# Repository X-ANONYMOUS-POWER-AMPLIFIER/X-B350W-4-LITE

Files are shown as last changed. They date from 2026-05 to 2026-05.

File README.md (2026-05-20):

# X-B350W-4-LITE - SIMPLIFIED MAIN-CIRCUIT MODULE OF 350 WATTS CLASS-B AUDIO POWER AMPLIFIER MAIN-CIRCUIT FOR 4-OHMS OUTPUT LOAD

X-B350W-4-LITE is a power amplifier main-circuit module designed to handle 350 watts of 4-ohms output load power rating. The circuit of X-B350W-4-LITE applies only the effective circuitry models for each of its blocks. Its input-stage applies a minimalist-but-effective LTP (Long Tailed Pair) circuit model, completed with an active-load and an offset null adjustment trimmer. Its VAS (Voltage Amplifier Stage) applies a simple circuit model but with an advanced active-load technique to achieve high amplification performance, with applies only few number of transistors without needing to apply differential-based topology.

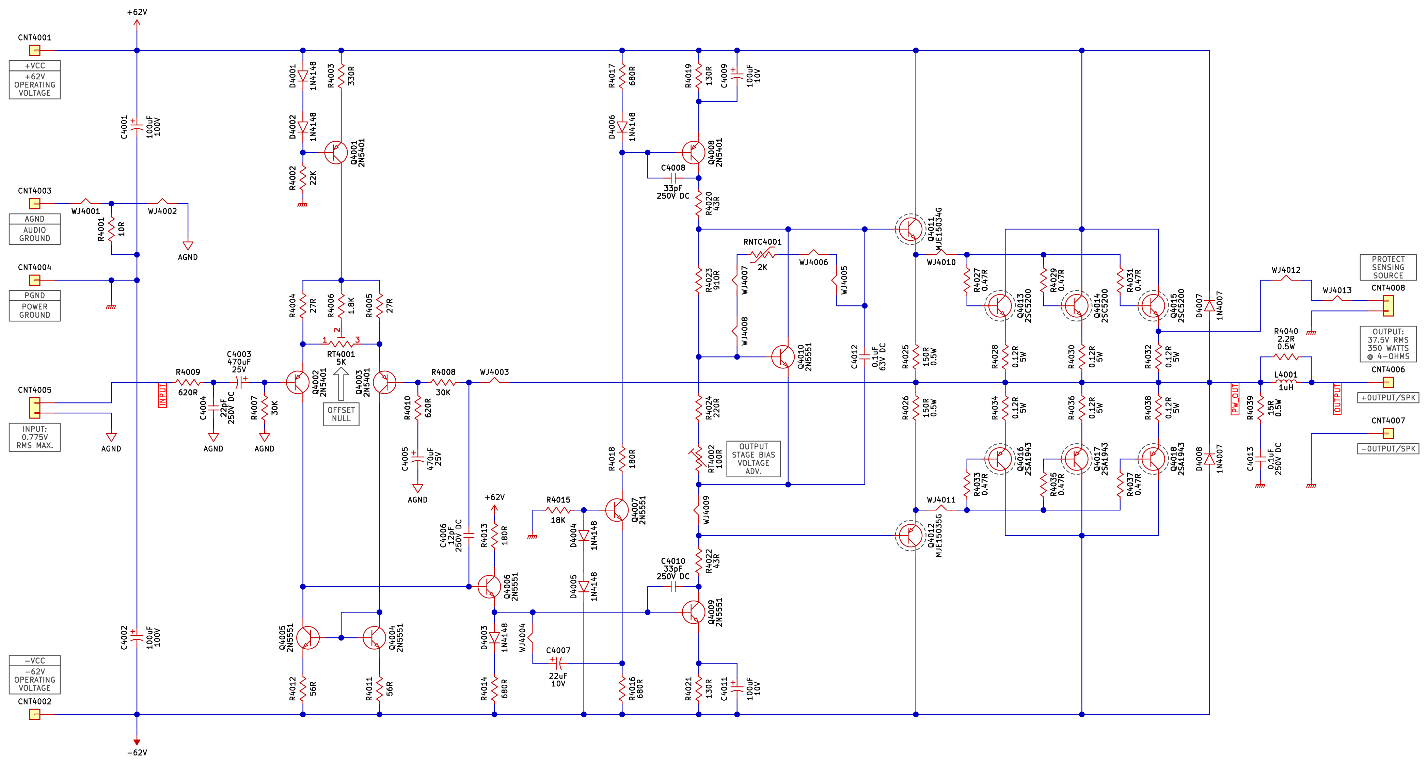
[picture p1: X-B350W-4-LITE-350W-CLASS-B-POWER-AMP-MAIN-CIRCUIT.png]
X-B350W-4-LITE schematic diagram


## Advanced VAS Model

The VAS of this power amp main-circuit model has an active load that synchronized with the main VAS side to be working as well a fully symmetrical VAS. The output signal from the LTP buffer (Q4006's emitter) copied by a grounded-base transistor amplifier or signal-current-buffer, Q4007, to feed a copy of signal for VAS's loader, Q4008, makes the VAS's loader to be fully actively working side-by-side with the main VAS, Q4009.

The amplification workflow between LTP buffer, Q4006, into the VAS loader, Q4008, isn't for tackling the DC amplification, but limited for tackling AC amplification. The LTP buffer output, Q4006's emitter, is coupled by C4007 into the emitter of Q4007 for gaining the AC signal only, thus Q4007 can keep its main function as a current-source to provide a constant forward-bias-current for Q4008's base and thus Q4008 also kept its function as a current-source for providing the initial constant forward-bias-current for the output-stage while it is also taking function as an active loader of VAS for providing fully symmetrical AC amplification.

There are 3 nodes of NFB lag compensations applied as C4006, C4008, and C4010, to achieve high performance in high frequency amplification (10kHz ~ 15kHz). C4006 compensates the NFB lag for LTP output buffer, Q4006, eliminates non-linear EF buffering. C4008 compensates the NFB lag for high-side VAS, Q4008, eliminates non-linear voltage amplification. C4010 compensates the NFB lag for low-side VAS, Q4009, eliminates non-linear voltage amplification.

By applying this technique, this power amp main-circuit model will be able to achieve wide headroom even for 1-ohms load in fully symmetrically and certainly achieve high performance in nominal output load (4-ohms or 8-ohms). And certainly, one of the important tings is about limit the number of transistors, makes the X-B350W-4-LITE circuit model quit simple with high performance guarantee.

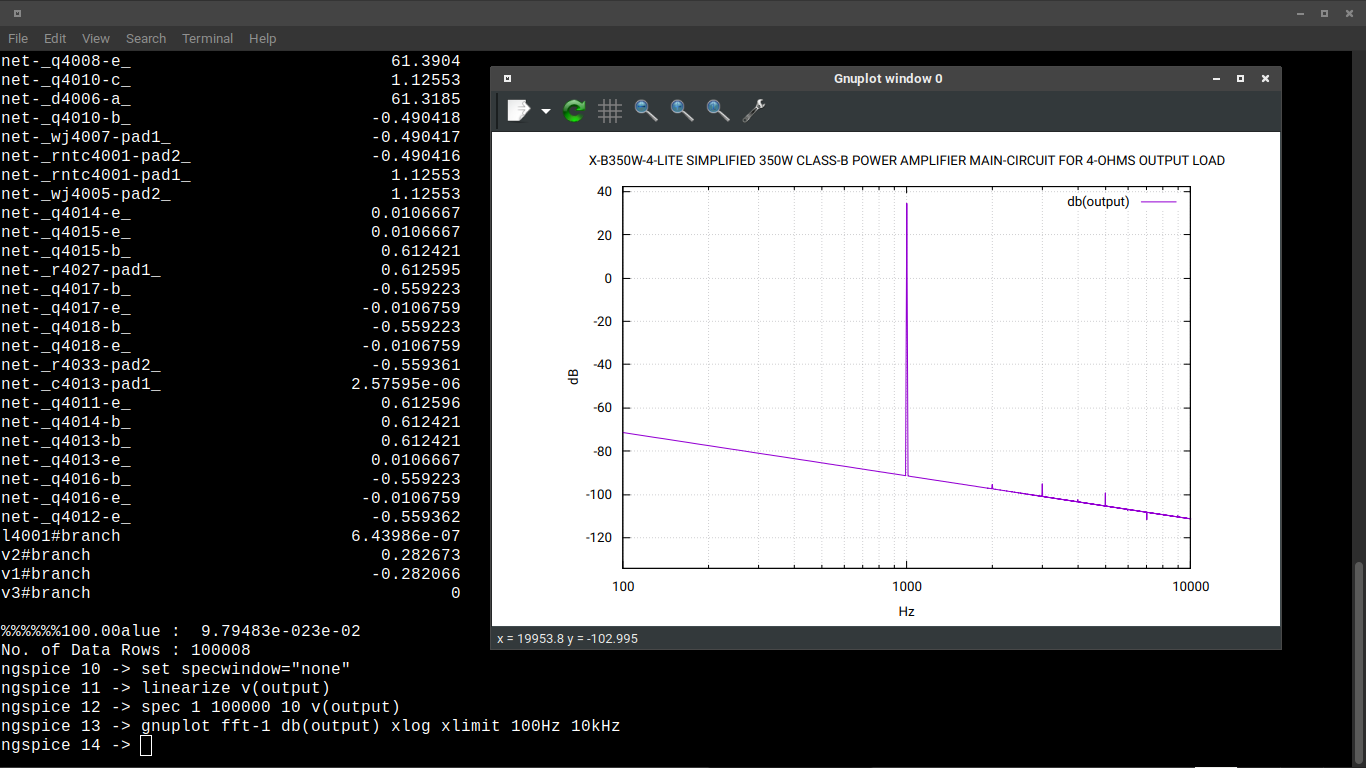
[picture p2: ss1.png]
FFT analysis 1

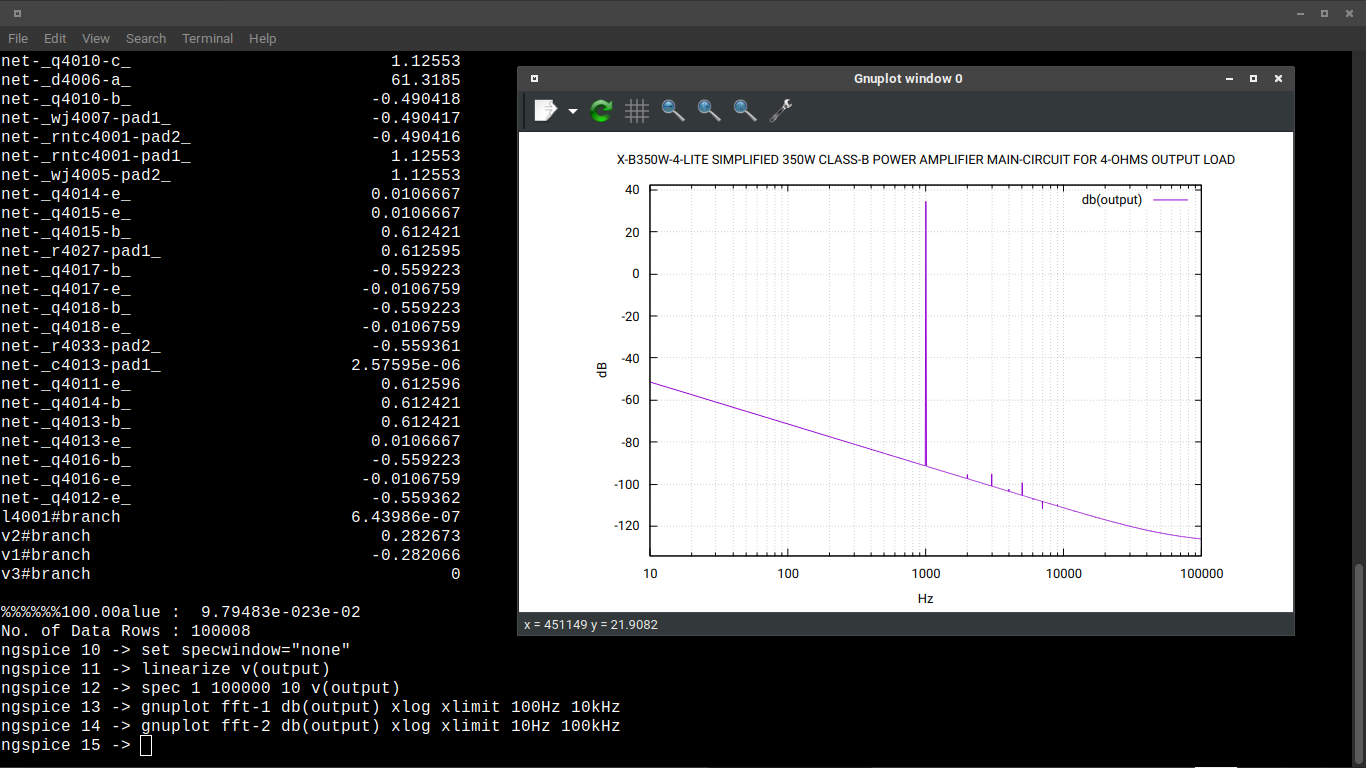
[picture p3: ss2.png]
FFT analysis 2

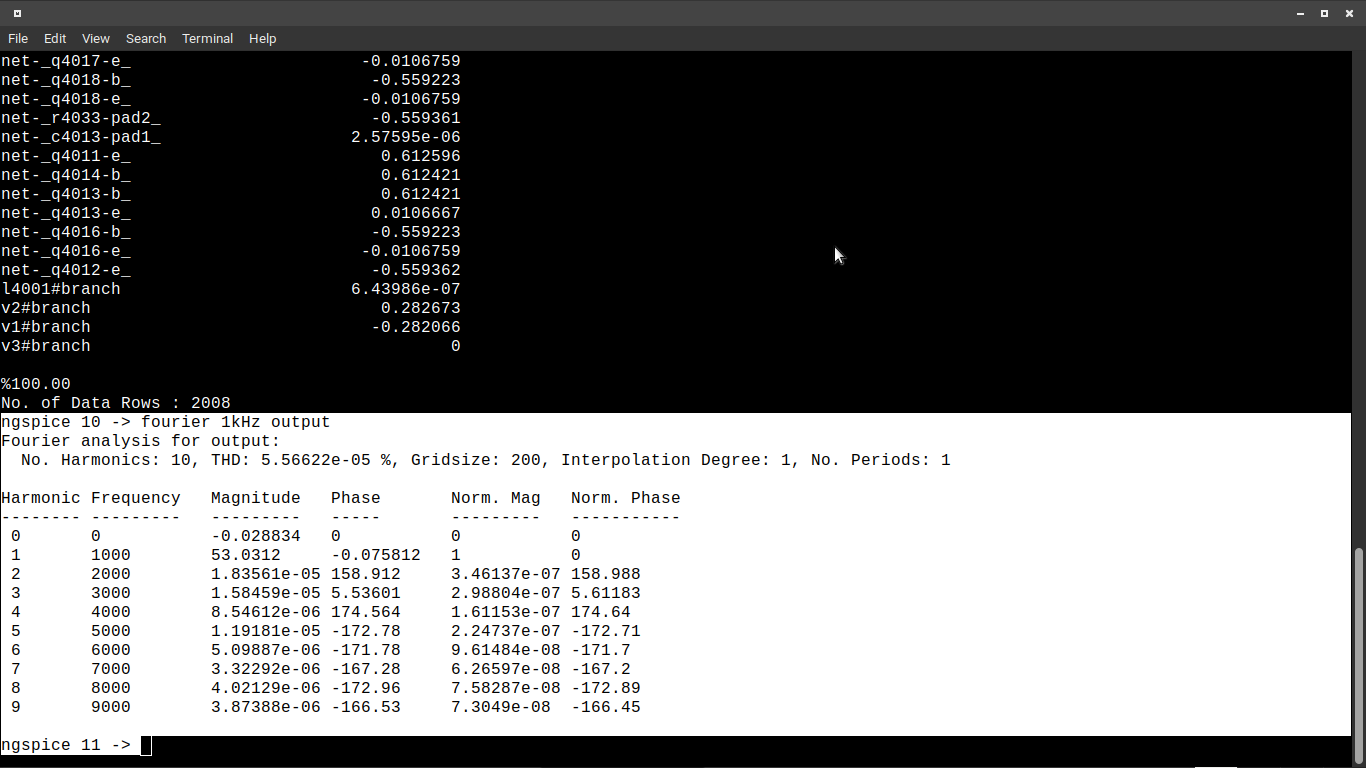
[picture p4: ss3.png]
Fourier analysis 1

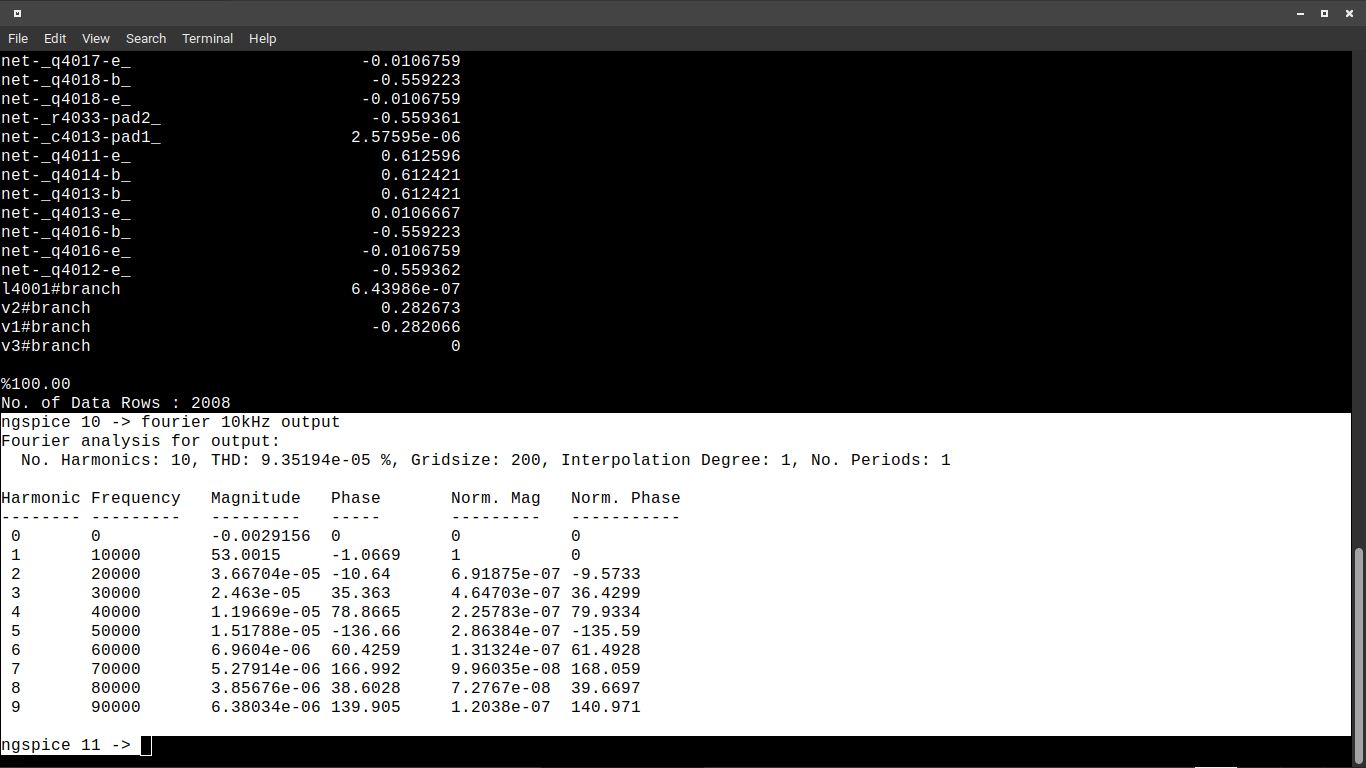
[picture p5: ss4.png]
Fourier analysis 2


## Warning: None of Current-Limiter Applied Within The Output-Stage

There is none of current-limiter applied within the output-stage, means that it may introduce a risk of short-circuited output. To prevent a fatal output short-circuited overcome, an output protection circuit have to be applied between the X-B350W-4-LITE module's +SPK output and the loudspeaker. The sensing signal of the overload output or output short-circuit can be obtained via CNT4008.

You may have a question, why none of current-limiter applied within the output-stage? The answer is: Applying the current-limiters within the output-stage, as it commonly applied "just to drop the signal amplitude of the output-stage driver transistor bases" - is not really effective since the VAS will always maintain its signal-current along to follow its amplification level although the current-limiter actives as it detects a short-circuited output.

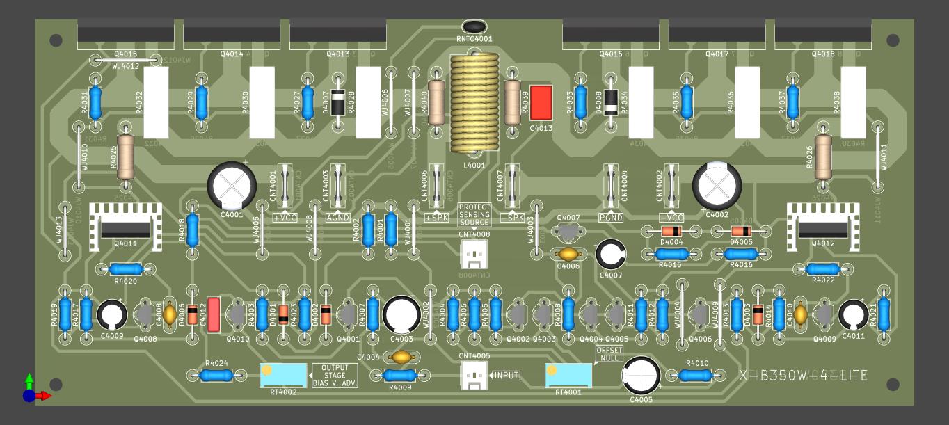
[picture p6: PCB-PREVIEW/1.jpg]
Circuit board preview 1

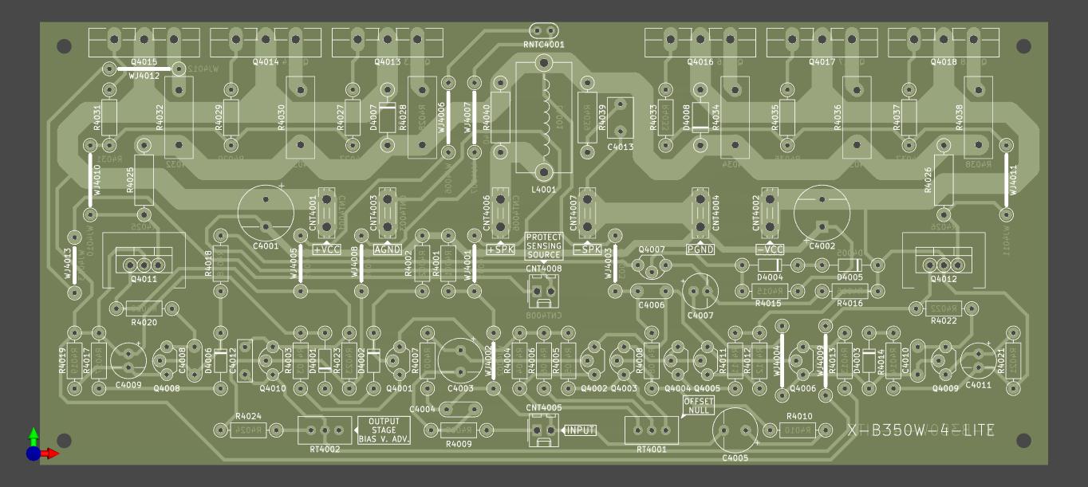
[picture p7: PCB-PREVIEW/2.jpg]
Circuit board preview 2

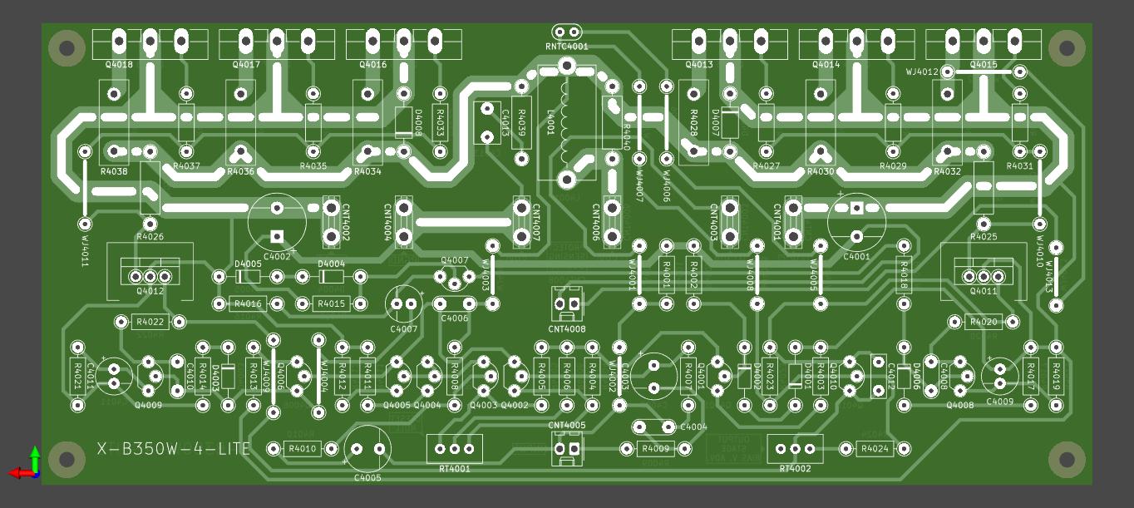
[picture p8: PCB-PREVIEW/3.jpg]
Circuit board preview 3

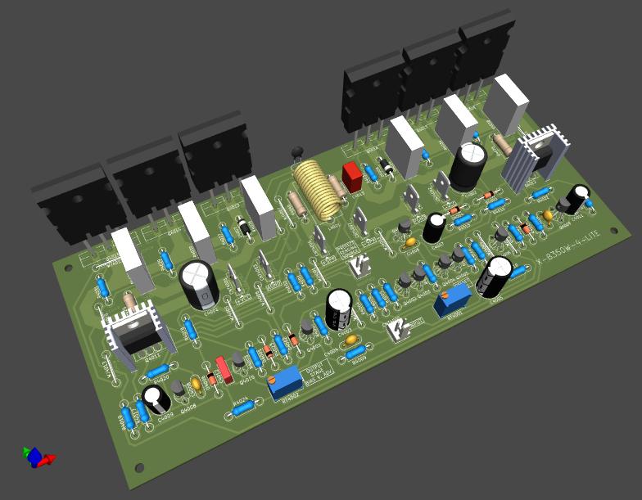
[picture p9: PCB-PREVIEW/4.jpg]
Circuit board preview 4

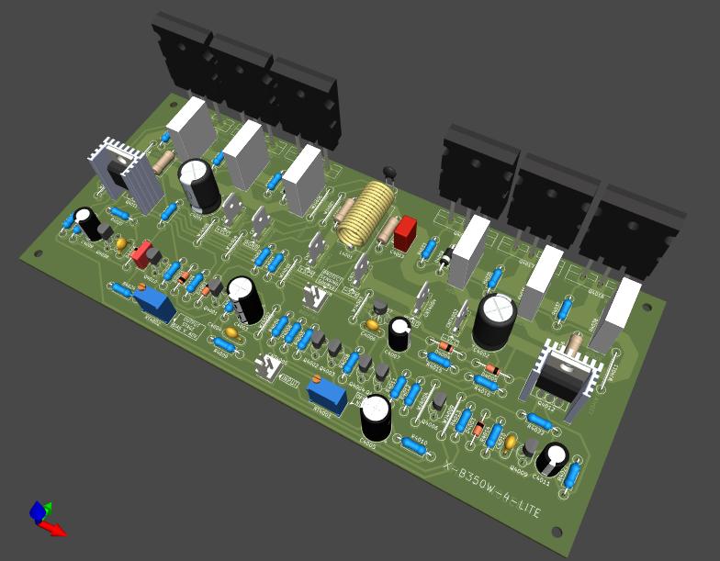
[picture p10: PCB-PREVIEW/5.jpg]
Circuit board preview 5


## License

1. **License Grant**  
The Licensor hereby grants you a worldwide, royalty-free, non-exclusive, perpetual license to use the circuit design for the non-commercial purposes only.
2. **Conditions**  
Attribution: You must provide credit to the original creator when distributing this circuit design.
3. **Disclaimer of Warranty**  
THE DESIGN IS PROVIDED "AS IS". THE LICENSOR MAKES NO WARRANTIES, EXPRESS OR IMPLIED, REGARDING THE DESIGN, INCLUDING BUT NOT LIMITED TO ANY IMPLIED WARRANTIES OF MERCHANTABILITY OR FITNESS FOR A PARTICULAR PURPOSE.
4. **Limitation of Liability**  
IN NO EVENT SHALL THE LICENSOR BE LIABLE FOR ANY DAMAGES, INCLUDING BUT NOT LIMITED TO DIRECT, INDIRECT, INCIDENTAL, OR CONSEQUENTIAL DAMAGES ARISING OUT OF THE USE OF THE DESIGN.

# Design Files Bundle Download

Design files bundle is available for download by follow the URL: [https://github.com/X-ANONYMOUS-POWER-AMPLIFIER/X-B350W-4-LITE/archive/refs/heads/main.zip](https://github.com/X-ANONYMOUS-POWER-AMPLIFIER/X-B350W-4-LITE/archive/refs/heads/main.zip)

The main design files of schematic and PCB design are in [KiCad](https://www.kicad.org/) V.9.x format.

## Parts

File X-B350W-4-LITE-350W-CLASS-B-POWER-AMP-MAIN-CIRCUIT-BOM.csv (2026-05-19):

Reference | Value | Rating | Description | MFR Number | Manufacturer | Qty
C4001,C4002 | 100uF | 100V | Aluminum Electrolytic Capacitors - Radial Leaded 100uF 100V | ECA-1EM100I | Panasonic | 2
C4003,C4005 | 470uF | 25V | Aluminum Electrolytic Capacitors - Radial Leaded 470uF 25V | EEU-FC1E471L | Panasonic | 2
C4004 | 22pF | 250V DC | Multilayer Ceramic Capacitors MLCC - Leaded 22PF 50V 5% 5.0MM | RDE5C1H220J0K1H03B | Murata | 1
C4006 | 12pF | 250V DC | Multilayer Ceramic Capacitors MLCC - Leaded 250V 22pF C0G 5% LS=5.08mm | C323C120JAG5TA | KEMET | 1
C4007 | 22uF | 10V | Aluminum Electrolytic Capacitors - Radial Leaded 10VDC 22uF POLARIZED | ECE-A1AKS220I | Panasonic | 1
C4008,C4010 | 33pF | 250V DC | Multilayer Ceramic Capacitors MLCC - Leaded 250V 33pF C0G 5% LS=5.08mm | C323C330JAG5TA | KEMET | 2
C4009,C4011 | 100uF | 10V | Aluminum Electrolytic Capacitors - Radial Leaded 100uF 10V | ECE-A1AKA101 | Panasonic | 2
C4012 | 0.1uF | 63V DC | Film Capacitors 0.1 uF 63 VDC 5% | MKS2C031001A00JI00 | WIMA | 1
C4013 | 0.1uF | 250V DC | Film Capacitors 0.1 uF 250 VDC 20% | MKS2F031001E00MSSD | WIMA | 1
CNT4001,CNT4002,CNT4003,CNT4004,CNT4006,CNT4007 | 2376582-2 |  | 250 FASTON PCB TAB TPBR | 2376582-2 | TE Connectivity | 6
CNT4005,CNT4008 | 22-27-2021 |  | Headers & Wire Housings 2 POS HEADER | 22-27-2021 | Molex | 2
D4001,D4002,D4003,D4004,D4005,D4006 | 1N4148 |  | Small Signal Switching Diodes Small Signal Diode, DO-35, 100V, 0.2A, 175C | 1N4148 | Diotec Semiconductor | 6
D4007,D4008 | 1N4007 |  | Rectifiers Diode, DO-41, 1000V, 1A | 1N4007 | Diotec Semiconductor | 2
L4001 | 1uH |  | Air Core Inductor, 16 windings, D = 8 mm, enameled wire diameter = 1.2 mm |  |  | 1
Q4001,Q4002,Q4003,Q4008 | 2N5401 |  | Bipolar Transistors - BJT PNP 160Vcbo 150Vceo 5.0Vebo 600mA 625mW | 2N5401 TIN/LEAD | Central Semiconductor | 4
Q4004,Q4005,Q4006,Q4007,Q4009,Q4010 | 2N5551 |  | Bipolar Transistors - BJT NPN 180Vcbo 160Vceo 6.0Vebo 600mA 625mW\ | 2N5551 TIN/LEAD | Central Semiconductor | 6
Q4011 | MJE15034G |  | Bipolar Transistors - BJT 4A 350V 50W NPN | MJE15034G | onsemi | 1
Q4012 | MJE15035G |  | Bipolar Transistors - BJT 4A 350V 50W PNP | MJE15035G | onsemi | 1
Q4013,Q4014,Q4015 | 2SC5200 |  | Bipolar Transistors - BJT NPN 230V 15A | 2SC5200-O(Q) | Toshiba | 3
Q4016,Q4017,Q4018 | 2SA1943 |  | Bipolar Transistors - BJT PNP 230V 15A | 2SA1943-O(Q) | Toshiba | 3
R4001 | 10R | 0.25W | Metal Film Resistors - Through Hole 10 OHM 1/4W 1% | MFR-25FRE52-10R | YAGEO | 1
R4002 | 22K | 0.25W | Metal Film Resistors - Through Hole 22K OHM 1/4W 1% | MFR-25FRE52-22K | YAGEO | 1
R4003 | 330R | 0.25W | Metal Film Resistors - Through Hole 330 OHM 1/4W 1% | MFR-25FRE52-330R | YAGEO | 1
R4004,R4005 | 27R | 0.25W | Metal Film Resistors - Through Hole 27 OHM 1/4W 1% | MFR-25FRE52-27R | YAGEO | 2
R4006 | 1.8K | 0.25W | Metal Film Resistors - Through Hole 1.8K OHM 1/4W 1% | MFR-25FRE52-1K8 | YAGEO | 1
R4007,R4008 | 30K | 0.25W | Metal Film Resistors - Through Hole 30K OHM 1/4W 1% | MFR-25FRE52-30K | YAGEO | 2
R4009,R4010 | 620R | 0.25W | Metal Film Resistors - Through Hole 620 OHM 1/4W 1% | MFR-25FRE52-620R | YAGEO | 2
R4011,R4012 | 56R | 0.25W | Metal Film Resistors - Through Hole 56 OHM 1/4W 1% | MFR-25FRE52-56R | YAGEO | 2
R4013,R4018 | 180R | 0.25W | Metal Film Resistors - Through Hole 180 OHM 1/4W 1% | MFR-25FRE52-180R | YAGEO | 2
R4014,R4016,R4017 | 680R | 0.25W | Metal Film Resistors - Through Hole 680 OHM 1/4W 1% | MFR-25FRE52-680R | YAGEO | 3
R4015 | 18K | 0.25W | Metal Film Resistors - Through Hole 18K OHM 1/4W 1% | MFR-25FRE52-18K | YAGEO | 1
R4019,R4021 | 130R | 0.25W | Metal Film Resistors - Through Hole 100 OHM 1/4W 1% | MFR-25FRE52-100R | YAGEO | 2
R4020,R4022 | 43R | 0.25W | Metal Film Resistors - Through Hole 680 OHM 1/4W 1% | MFR-25FRE52-680R | YAGEO | 2
R4023 | 910R | 0.25W | Metal Film Resistors - Through Hole 680 OHM 1/4W 1% | MFR-25FRE52-680R | YAGEO | 1
R4024 | 220R | 0.25W | Metal Film Resistors - Through Hole 180 OHM 1/4W 1% | MFR-25FRE52-180R | YAGEO | 1
R4025,R4026 | 150R | 0.5W | Metal Film Resistors - Through Hole 150 OHM 1/5W 1% | MFR-50FTE52-150R | YAGEO | 2
R4027,R4029,R4031,R4033,R4035,R4037 | 0.47R | 0.25W | Metal Oxide Resistors RSS1/2 .47 5%TR | MOSX1/2CT52RR47J | KOA Speer | 6
R4028,R4030,R4032,R4034,R4036,R4038 | 0.12R | 5W | Current Sense Resistors - Through Hole 0.12 Ohm 5W 5% 350ppm | BPR58CR12J | KOA Speer | 6
R4039 | 15R | 0.5W | Metal Film Resistors - Through Hole 15 OHM 1/5W 1% | MFR-50FTE52-15R | YAGEO | 1
R4040 | 2.2R | 0.5W | Metal Film Resistors - Through Hole 2.2 OHM 1/5W 1% | MFR-50FTE52-2R2 | YAGEO | 1
RNTC4001 | 2K |  | NTC Thermistors 2Kohm/2% 3528/0.5% | NTCLE100E3202GB0A | Vishay / BC Components | 1
RT4001 | 5K |  | Trimmer Resistors - Through Hole 3/8" 5Kohms Sealed Vertical Adjust | 3296W-1-502ALF | Bourns | 1
RT4002 | 100R |  | Trimmer Resistors - Through Hole 3/8" 100 ohms Sealed Vertical Adjust | 3296W-1-101ALF | Bourns | 1
WJ4001,WJ4002,WJ4003,WJ4004,WJ4005,WJ4006,WJ4007,WJ4008,WJ4009,WJ4010,WJ4011,WJ4012,WJ4013 | Wire Jumper |  | Wire Jumper |  |  | 13

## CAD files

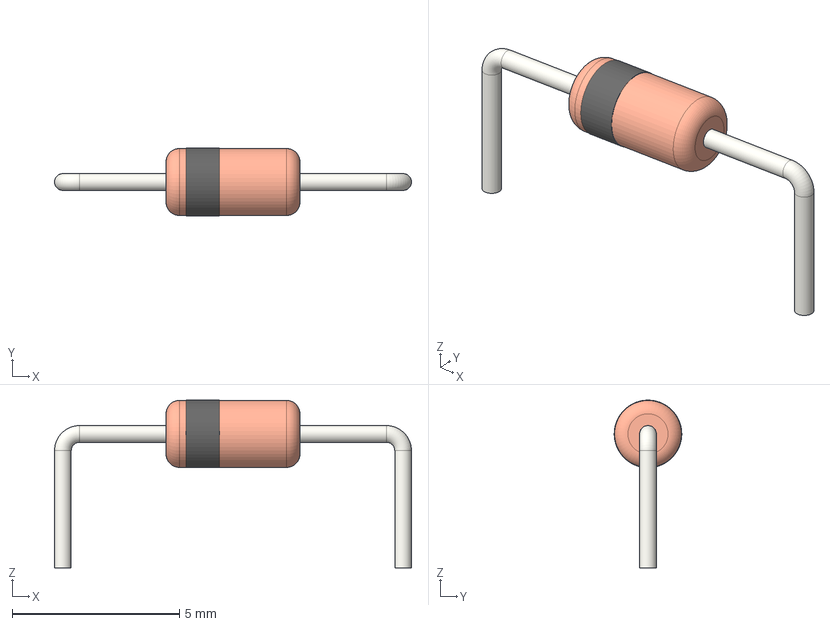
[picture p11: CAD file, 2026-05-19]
3D-FOOTPRINTS/D_DO-35_SOD27_P10.16mm_Horizontal.step
10.7 x 2.02 x 5.01 mm

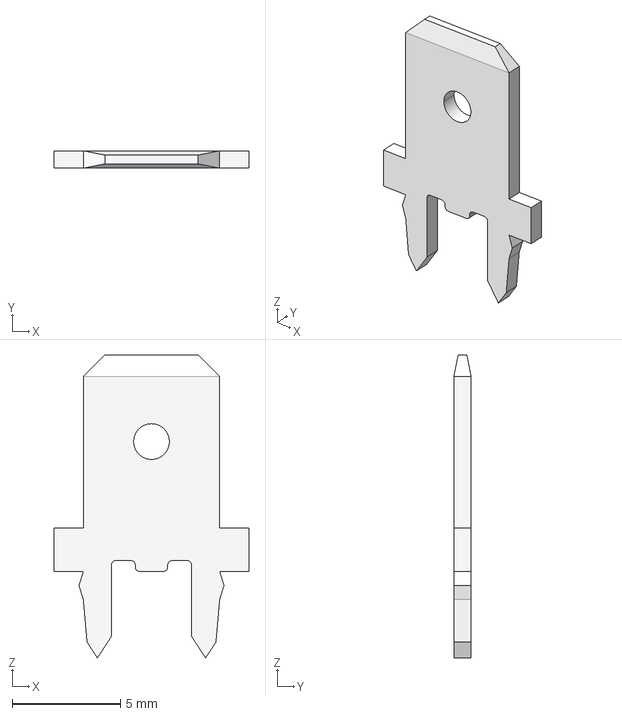
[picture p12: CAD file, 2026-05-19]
3D-FOOTPRINTS/c-2376582-2-a-3d.stp
9.00 x 0.8 x 14.0 mm

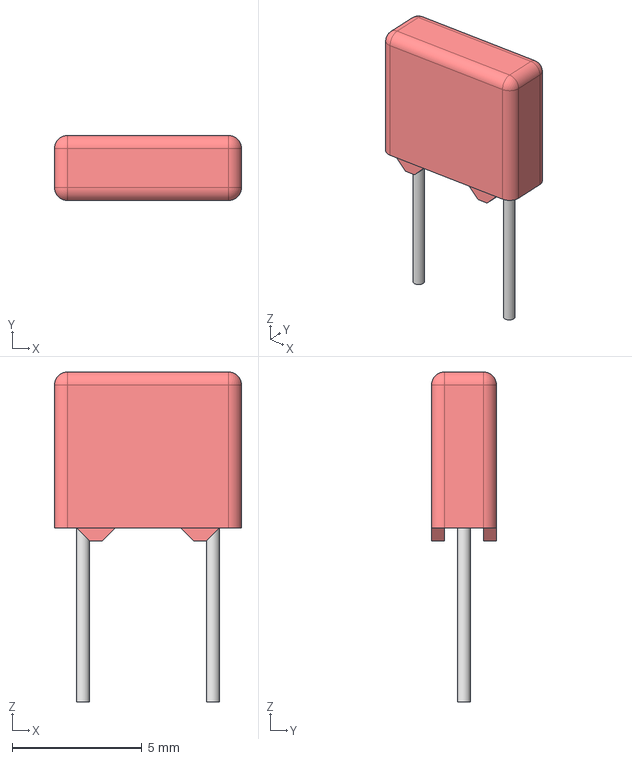
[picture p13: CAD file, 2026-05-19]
3D-FOOTPRINTS/FILM_RED_P500L720W250H650PD50.step
7.20 x 2.50 x 12.7 mm

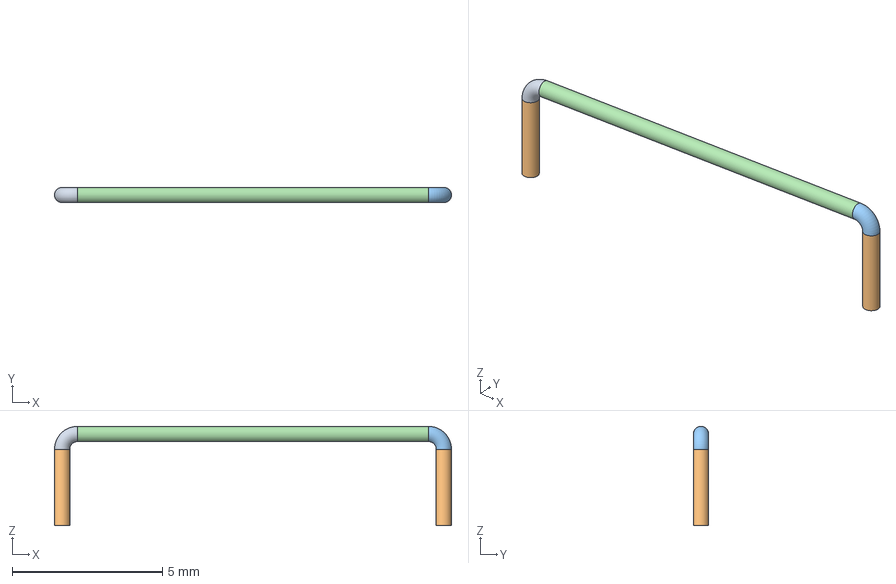
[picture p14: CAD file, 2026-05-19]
3D-FOOTPRINTS/J_12.7mm.step
13.2 x 0.508 x 3.30 mm

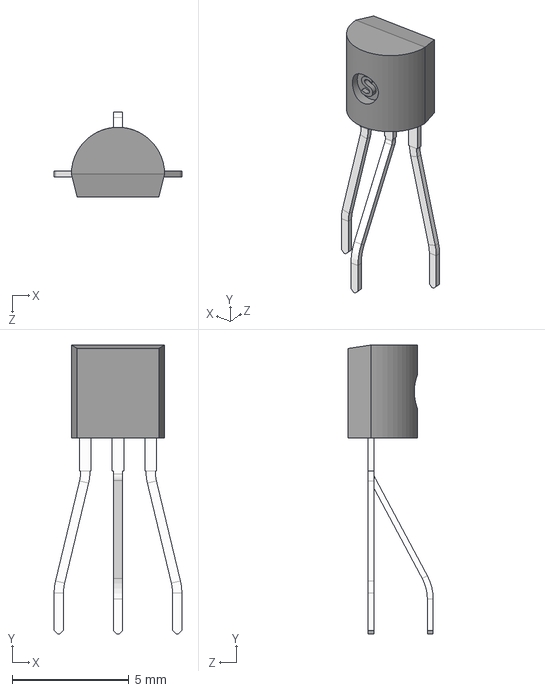
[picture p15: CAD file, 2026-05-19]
3D-FOOTPRINTS/TO-92.STEP
5.48 x 12.4 x 3.66 mm

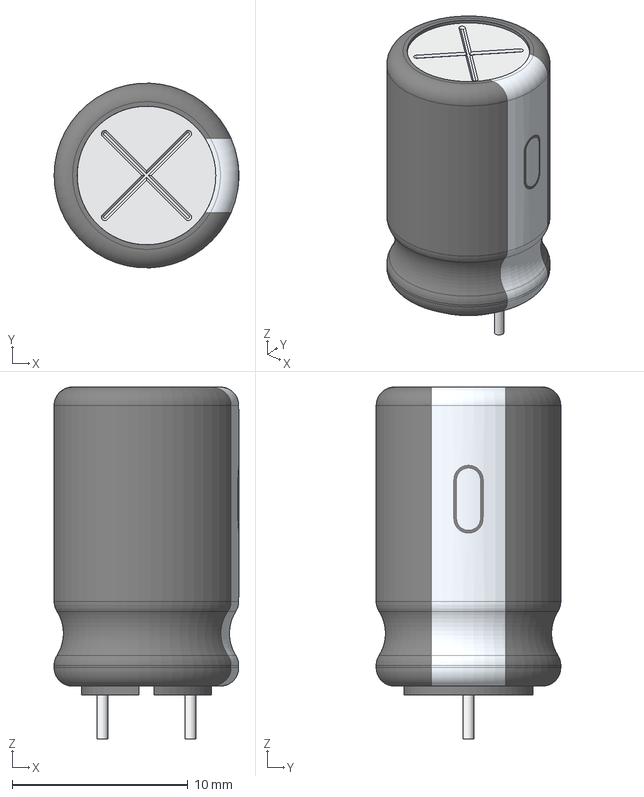
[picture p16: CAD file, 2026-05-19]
3D-FOOTPRINTS/CAP_RAD_D10x16_POL_BK.stp
10.5 x 10.5 x 20.0 mm

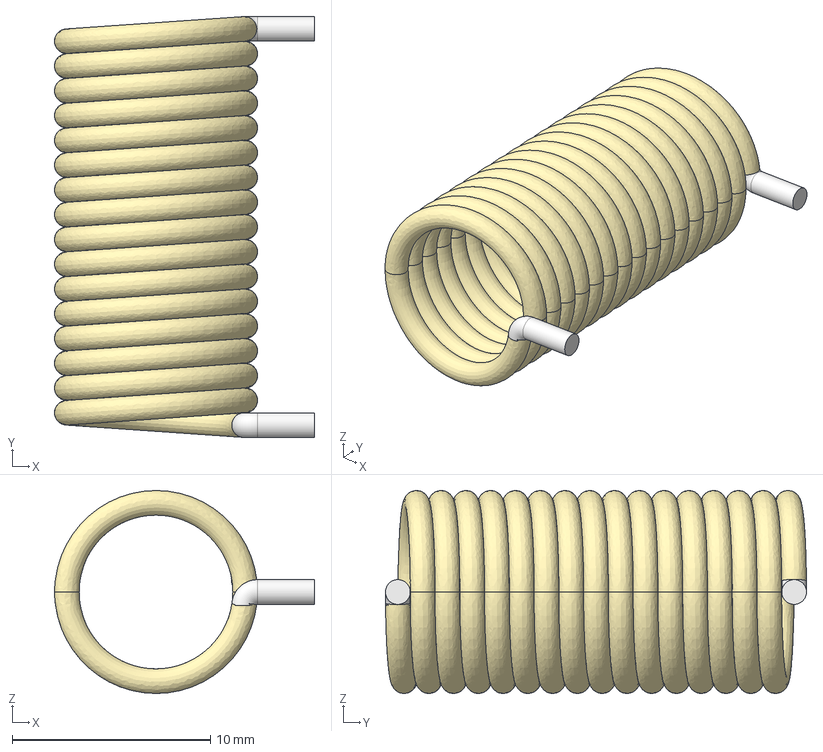
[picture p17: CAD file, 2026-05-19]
3D-FOOTPRINTS/INDUCTOR_AIR_CORE_1uH.step
13.1 x 21.2 x 10.2 mm
Slice.0

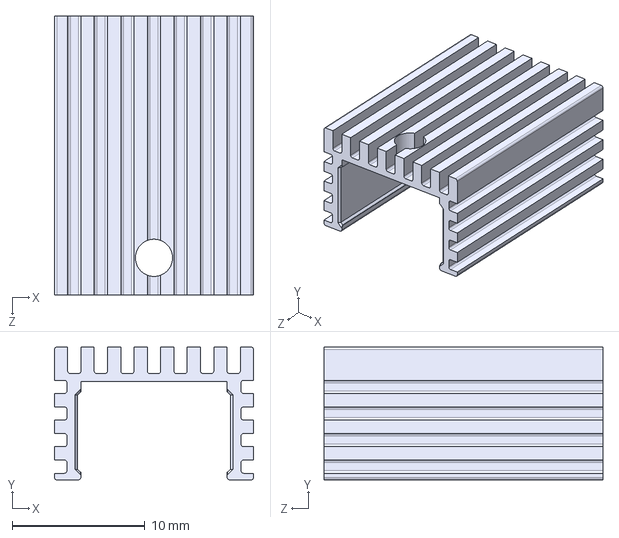
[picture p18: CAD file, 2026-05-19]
3D-FOOTPRINTS/TO220 Heatsink.STEP
15.0 x 10.0 x 21.0 mm

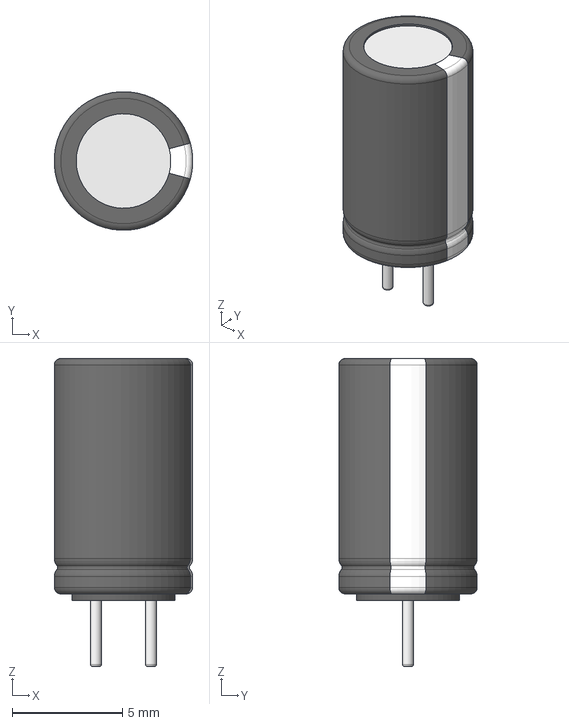
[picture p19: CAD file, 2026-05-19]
3D-FOOTPRINTS/Aluminum_electrolytic_capacitor_radial_D6.3_H11_PinD0.5_Pitch2.5_nominal_black.step
6.29 x 6.30 x 14.0 mm

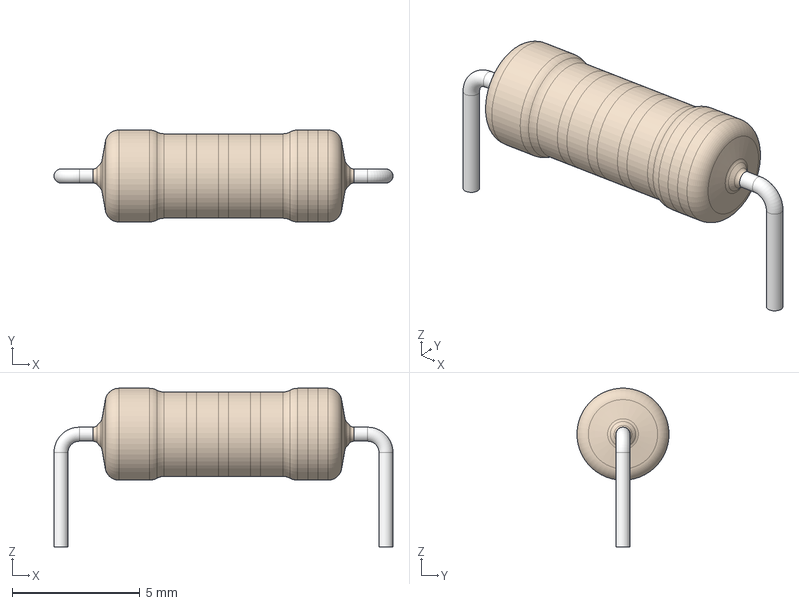
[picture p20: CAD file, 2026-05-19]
3D-FOOTPRINTS/RES-0.5W-H-MO.stp
13.2 x 3.60 x 6.20 mm
RES-0.5W-H-MO
RES-0.5W-H-MO001
RES-0.5W-H-MO002

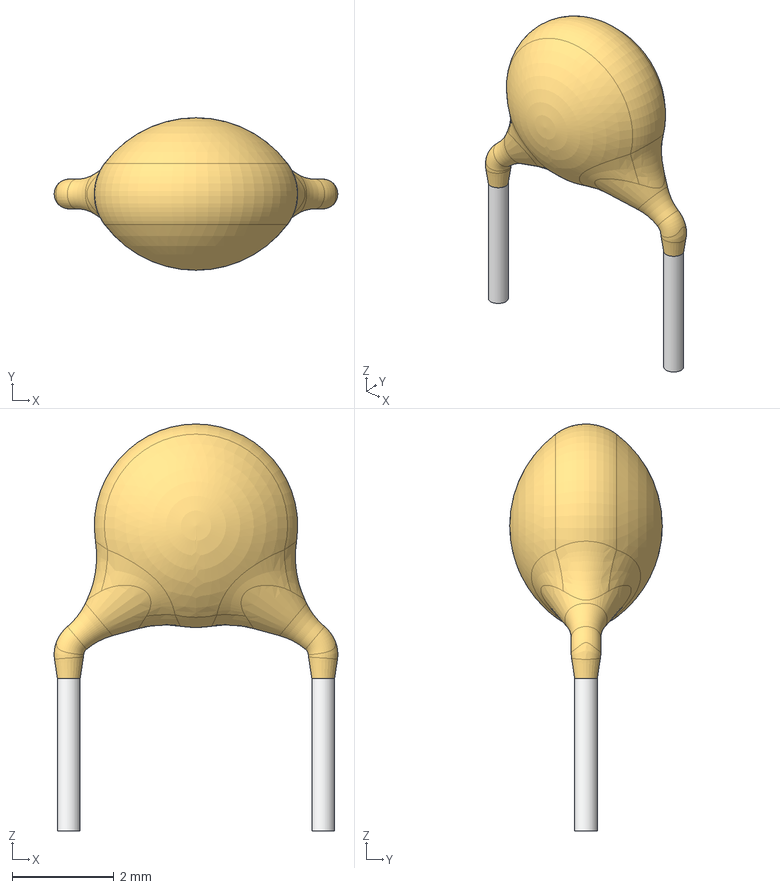
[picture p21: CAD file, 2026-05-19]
3D-FOOTPRINTS/CAP_DISC_4x3_YL.stp
5.58 x 3.00 x 8.00 mm
CAP_DISC_4x3_YL
CAP_DISC_4x3_YL001
CAP_DISC_4x3_YL002

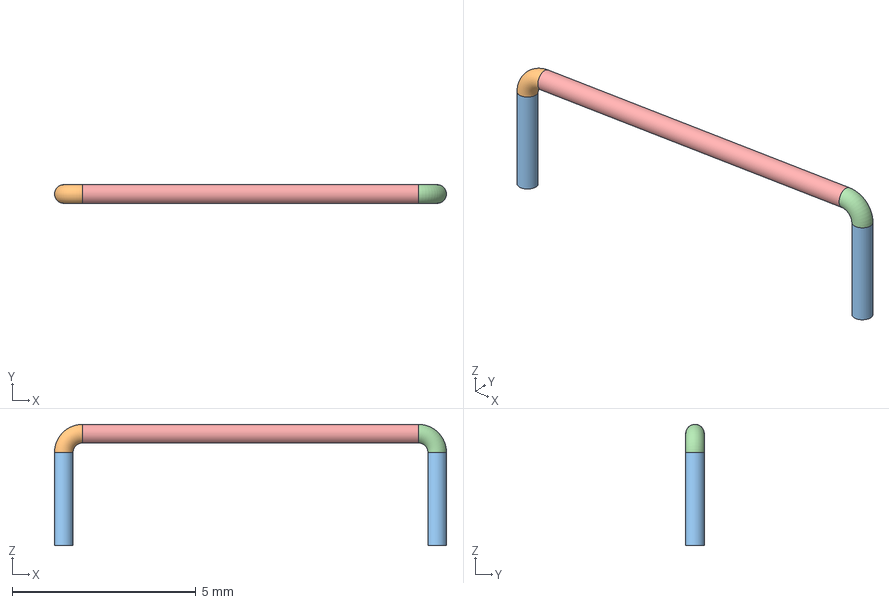
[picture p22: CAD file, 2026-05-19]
3D-FOOTPRINTS/J_10.16mm.step
10.7 x 0.508 x 3.30 mm
Circle
Arc
Circle003
Line
Circle004
Arc001
Circle005
Line002
Circle002
Line001

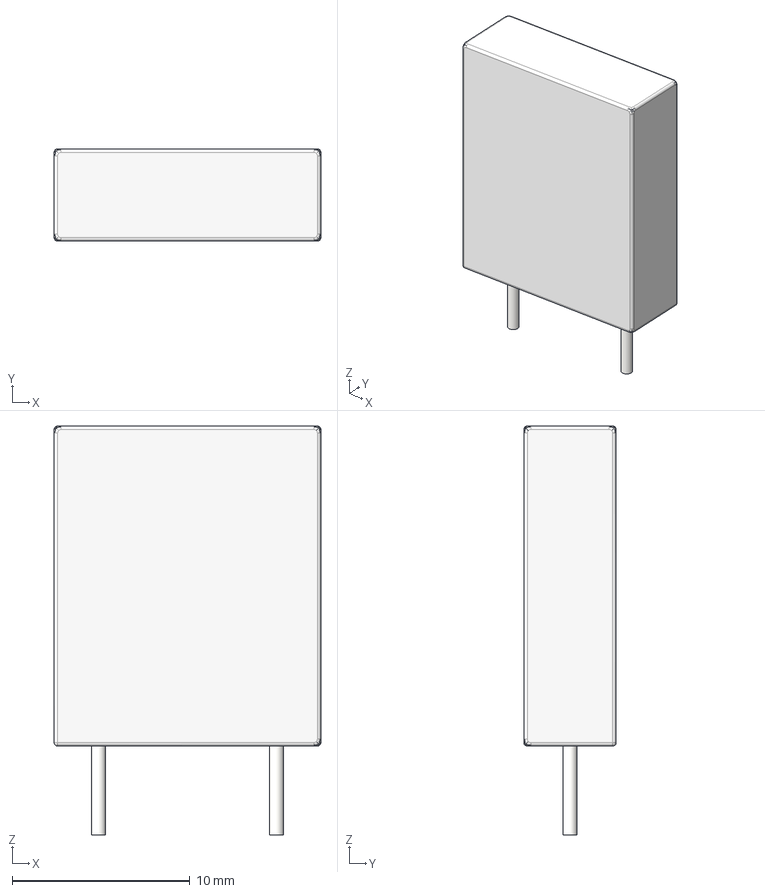
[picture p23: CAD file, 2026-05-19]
3D-FOOTPRINTS/BPR-cement-resistor.step
15.0 x 5.20 x 23.0 mm

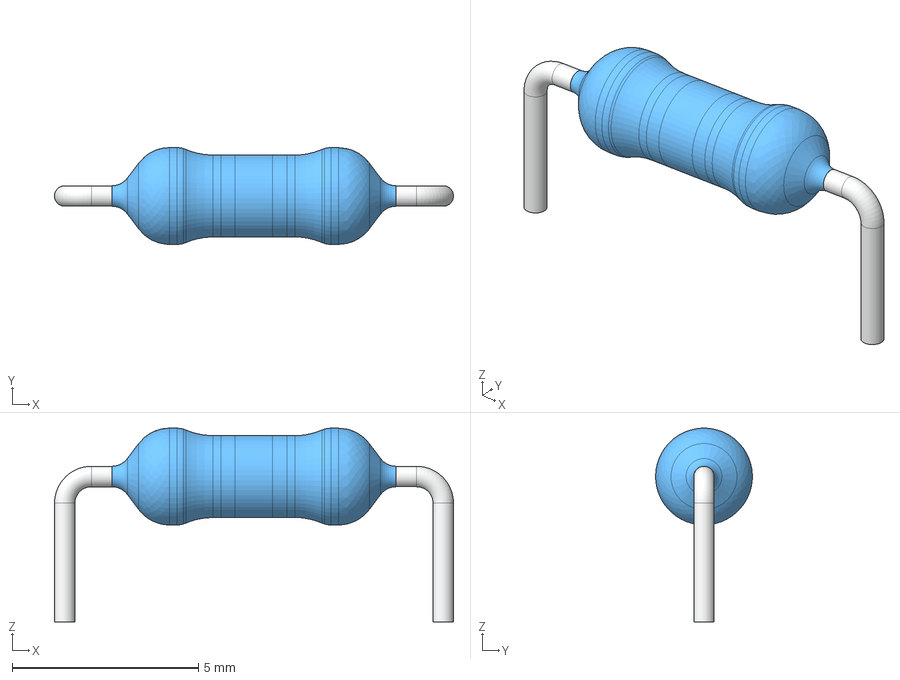
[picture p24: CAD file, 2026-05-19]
3D-FOOTPRINTS/RES-0.25W-H-CF.stp
10.7 x 2.60 x 5.20 mm
RES-0.25W-H-CF
RES-0.25W-H-CF001
RES-0.25W-H-CF002

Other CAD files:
3D-FOOTPRINTS/NTC.step
3D-FOOTPRINTS/470uF 25V electr 8 x16mm -P.diameter 4mm-Black-White.stp

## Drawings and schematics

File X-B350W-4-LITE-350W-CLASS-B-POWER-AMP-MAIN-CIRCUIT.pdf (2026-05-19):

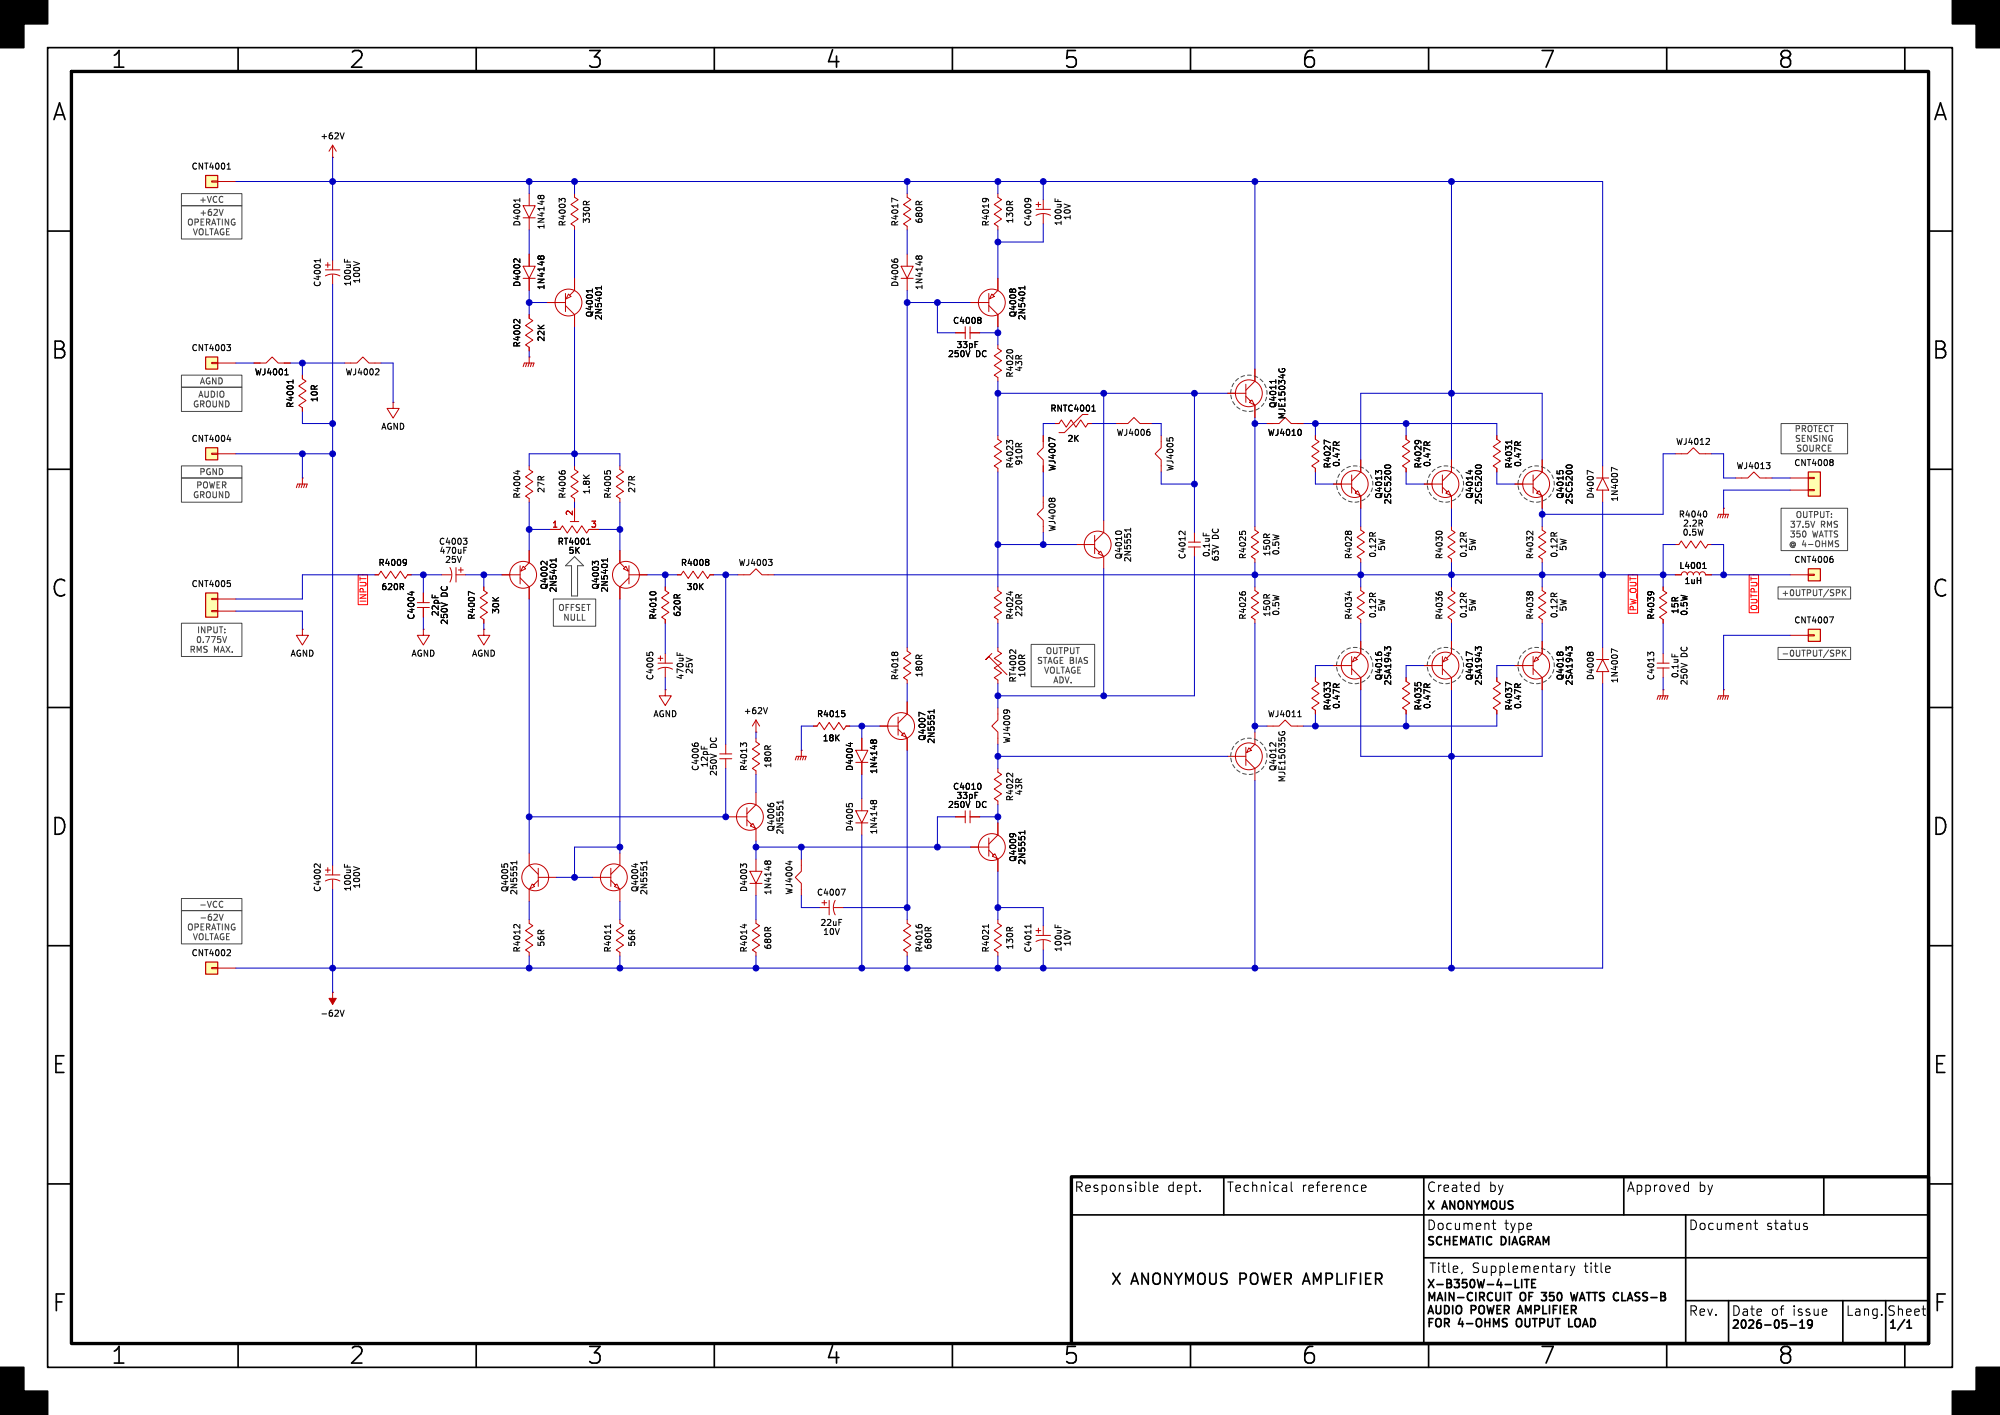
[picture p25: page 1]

SOURCE OUTPUT STAGE BIAS

X ANONYMOUS

SCHEMATIC DIAGRAM

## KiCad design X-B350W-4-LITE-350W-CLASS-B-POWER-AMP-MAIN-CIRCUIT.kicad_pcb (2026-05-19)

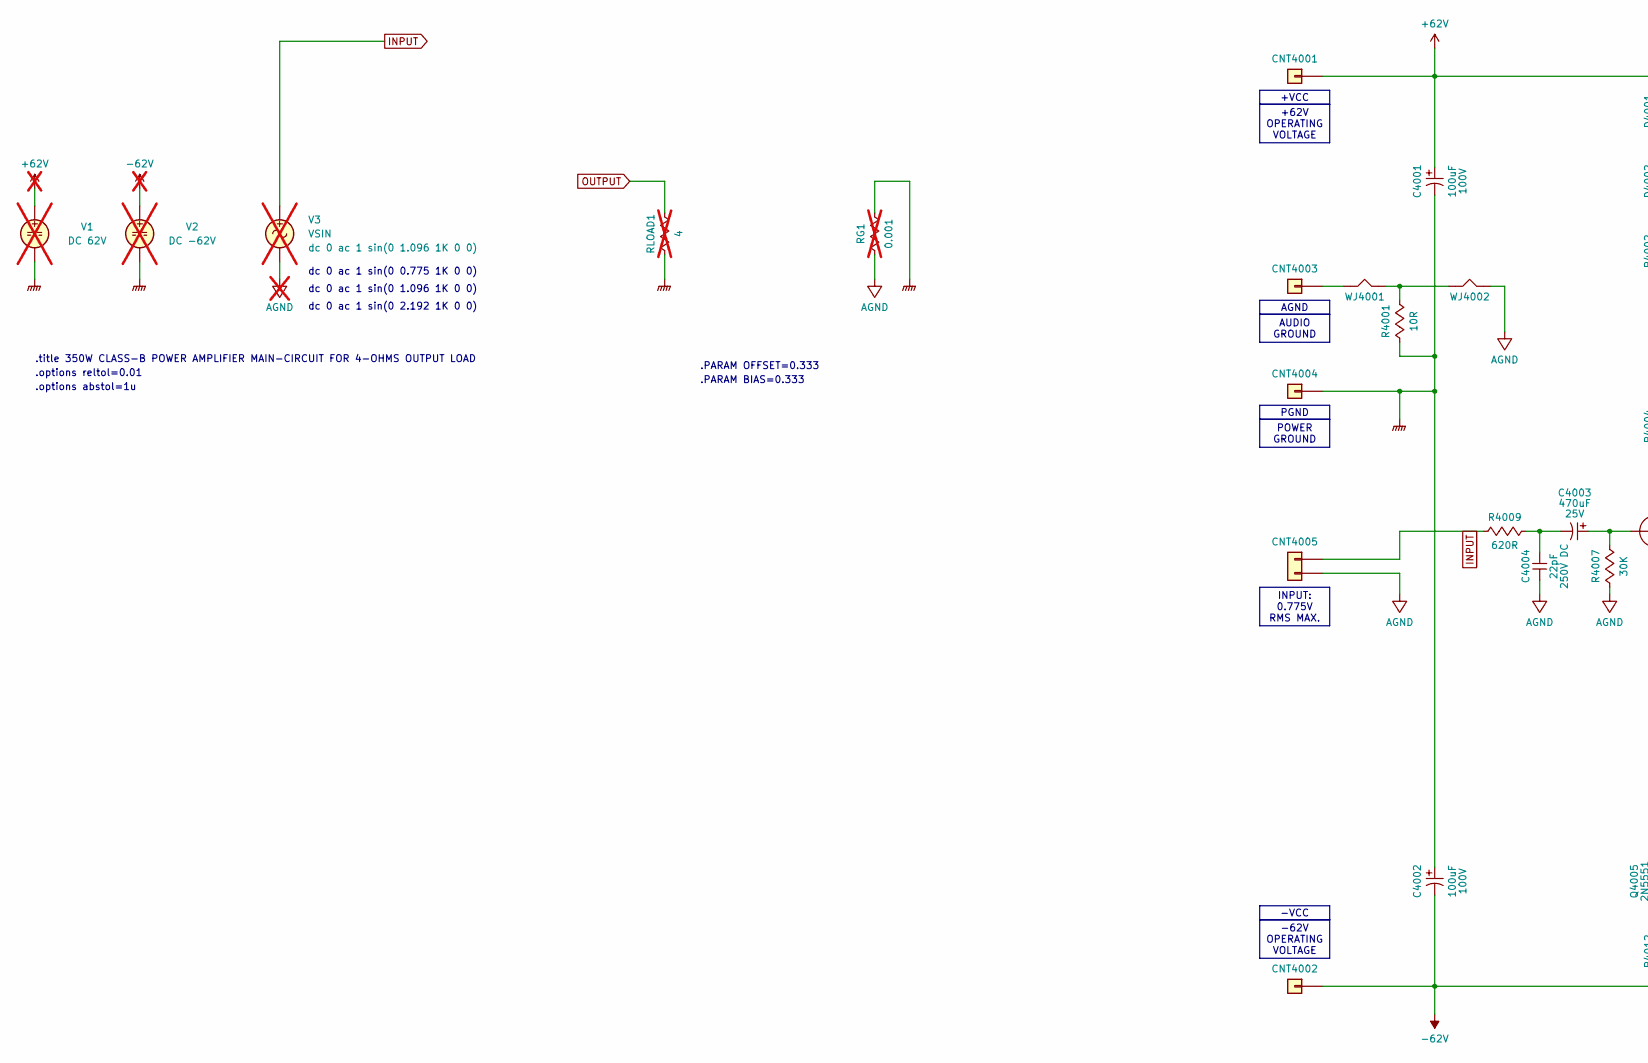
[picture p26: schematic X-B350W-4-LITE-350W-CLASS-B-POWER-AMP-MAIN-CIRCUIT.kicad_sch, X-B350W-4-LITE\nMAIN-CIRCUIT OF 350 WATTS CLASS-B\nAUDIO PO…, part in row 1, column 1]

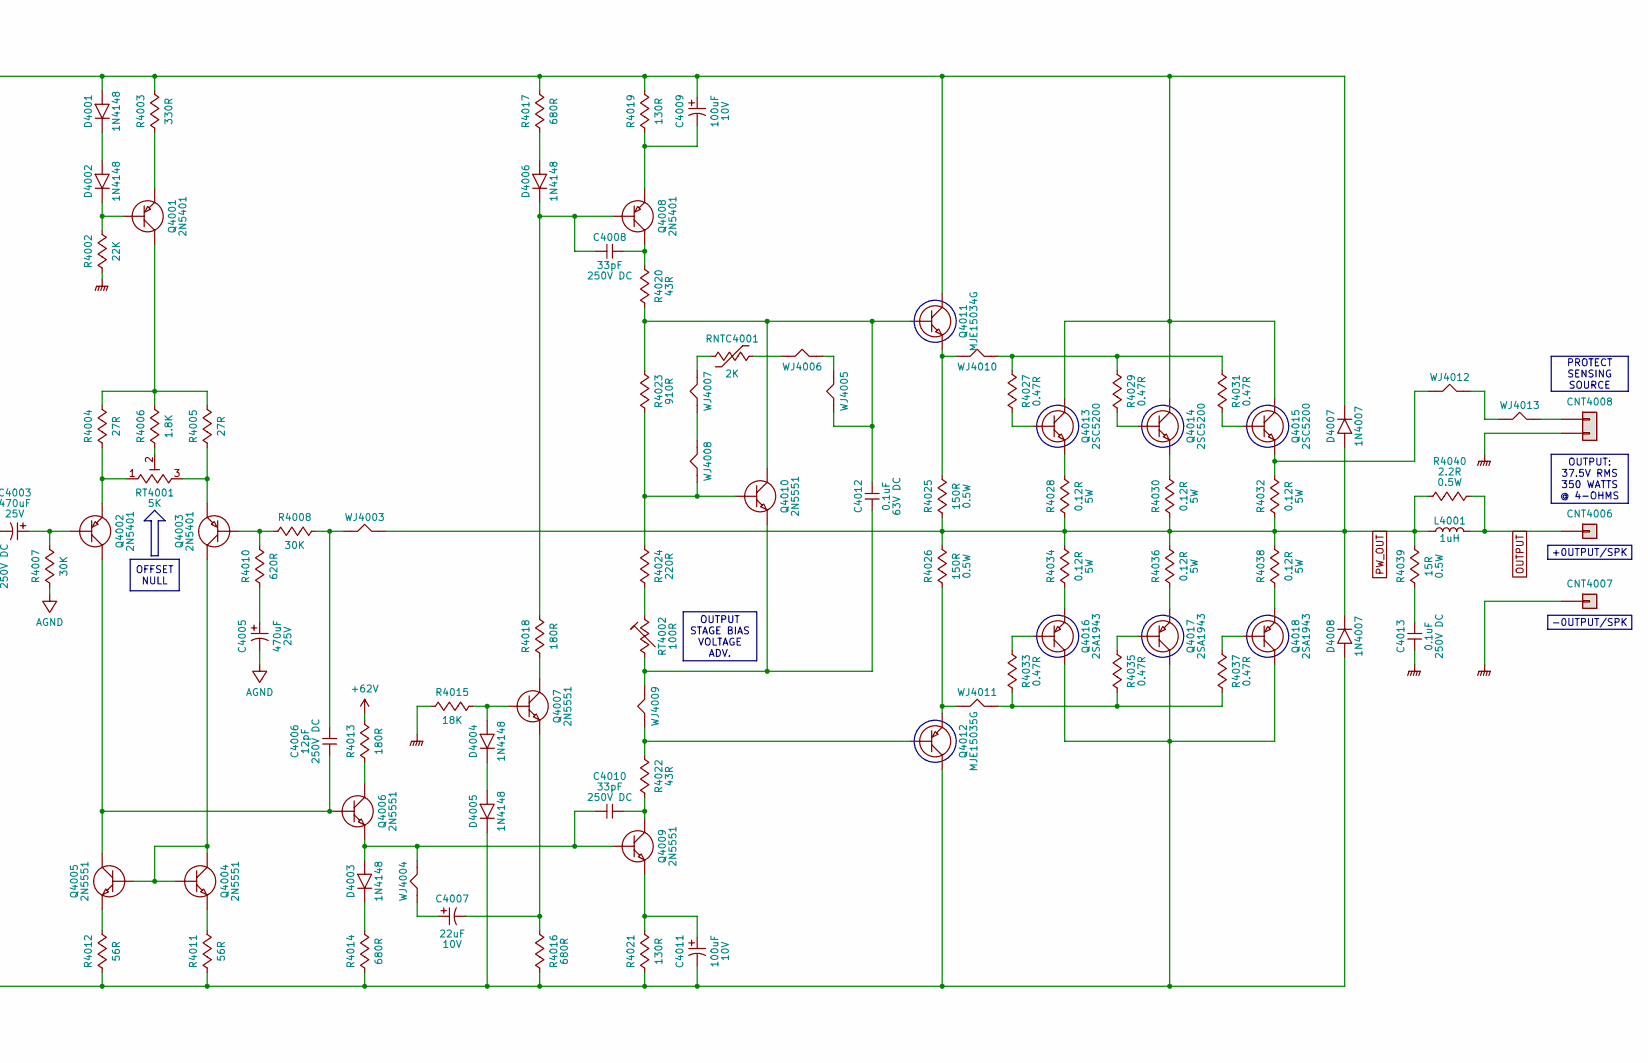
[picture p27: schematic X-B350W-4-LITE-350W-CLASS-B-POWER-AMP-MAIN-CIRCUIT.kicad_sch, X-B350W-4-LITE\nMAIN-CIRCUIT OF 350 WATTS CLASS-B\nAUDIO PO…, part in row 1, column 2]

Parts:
C4001, C4002: 100uF; CP_Radial_D10.0mm_P5.00mm; Rating 100V
C4003, C4005: 470uF; CP_Radial_D8.0mm_P4.00mm_P5.00mm; Rating 25V
C4004: 22pF; C_Disc_D7.5mm_W2.5mm_P5.08mm; Rating 250V DC
C4006: 12pF; C_Disc_D7.5mm_W2.5mm_P5.08mm; Rating 250V DC
C4007: 22uF; CP_Radial_D6.3mm_P2.50mm; Rating 10V
C4008, C4010: 33pF; C_Disc_D7.5mm_W2.5mm_P5.08mm; Rating 250V DC
C4009, C4011: 100uF; CP_Radial_D6.3mm_P2.50mm; Rating 10V
C4012: 0.1uF; C_Rect_L7.5mm_W2.5mm_P5.00mm_WIMA_MKS2; Rating 63V DC
C4013: 0.1uF; C_Rect_L7.2mm_W4.5mm_P5.00mm_FKS2_FKP2_MKS2_MKP2; Rating 250V DC
CNT4001, CNT4002, CNT4003, CNT4004, CNT4006, CNT4007: 2376582-2; PCB_TAB_250_FASTON_TPBR
CNT4005, CNT4008: 22-27-2021; Molex_KK-254_AE-6410-02A_1x02_P2.54mm_Vertical
D4001, D4002, D4003, D4004, D4005, D4006: 1N4148; D_DO-35_SOD27_P10.16mm_Horizontal
D4007, D4008: 1N4007; D_DO-41_SOD81_P10.16mm_Horizontal
L4001: 1uH; Inductor_Air_Core_1uH
Q4001, Q4002, Q4003, Q4008: 2N5401; TO-92_3_Wide
Q4004, Q4005, Q4006, Q4007, Q4009, Q4010: 2N5551; TO-92_3_Wide
Q4011: MJE15034G; TO-220-3_Vertical_With_Small_Heatsink
Q4012: MJE15035G; TO-220-3_Vertical_With_Small_Heatsink
Q4013, Q4014, Q4015: 2SC5200; TO-264-3_Vertical
Q4016, Q4017, Q4018: 2SA1943; TO-264-3_Vertical
R4001: 10R; R_Axial_DIN0207_L6.3mm_D2.5mm_P10.16mm; Rating 0.25W
R4002: 22K; R_Axial_DIN0207_L6.3mm_D2.5mm_P10.16mm; Rating 0.25W
R4003: 330R; R_Axial_DIN0207_L6.3mm_D2.5mm_P10.16mm; Rating 0.25W
R4004, R4005: 27R; R_Axial_DIN0207_L6.3mm_D2.5mm_P10.16mm; Rating 0.25W
R4006: 1.8K; R_Axial_DIN0207_L6.3mm_D2.5mm_P10.16mm; Rating 0.25W
R4007, R4008: 30K; R_Axial_DIN0207_L6.3mm_D2.5mm_P10.16mm; Rating 0.25W
R4009, R4010: 620R; R_Axial_DIN0207_L6.3mm_D2.5mm_P10.16mm; Rating 0.25W
R4011, R4012: 56R; R_Axial_DIN0207_L6.3mm_D2.5mm_P10.16mm; Rating 0.25W
R4013, R4018: 180R; R_Axial_DIN0207_L6.3mm_D2.5mm_P10.16mm; Rating 0.25W
R4014, R4016, R4017: 680R; R_Axial_DIN0207_L6.3mm_D2.5mm_P10.16mm; Rating 0.25W
R4015: 18K; R_Axial_DIN0207_L6.3mm_D2.5mm_P10.16mm; Rating 0.25W
R4019, R4021: 130R; R_Axial_DIN0207_L6.3mm_D2.5mm_P10.16mm; Rating 0.25W
R4020, R4022: 43R; R_Axial_DIN0207_L6.3mm_D2.5mm_P10.16mm; Rating 0.25W
R4023: 910R; R_Axial_DIN0207_L6.3mm_D2.5mm_P10.16mm; Rating 0.25W
R4024: 220R; R_Axial_DIN0207_L6.3mm_D2.5mm_P10.16mm; Rating 0.25W
R4025, R4026: 150R; R_Axial_DIN0309_L9.0mm_D3.2mm_P12.70mm; Rating 0.5W
R4027, R4029, R4031, R4033, R4035, R4037: 0.47R; R_Axial_DIN0207_L6.3mm_D2.5mm_P10.16mm; Rating 0.25W
R4028, R4030, R4032, R4034, R4036, R4038: 0.12R; R_BPR_5W; Rating 5W
R4039: 15R; R_Axial_DIN0309_L9.0mm_D3.2mm_P12.70mm; Rating 0.5W
R4040: 2.2R; R_Axial_DIN0309_L9.0mm_D3.2mm_P12.70mm; Rating 0.5W
RG1: 0.001; R_Axial_DIN0207_L6.3mm_D2.5mm_P10.16mm; Rating 0.25W; not fitted
RLOAD1: 4; R_Axial_DIN0207_L6.3mm_D2.5mm_P10.16mm; Rating 0.25W; not fitted
RNTC4001: 2K; NTC_D5.0mm_T2.5mm_SP2.50mm_Flip_Mount
RT4001: 5K; Potentiometer_Bourns_3296W_Vertical
RT4002: 100R; Potentiometer_Bourns_3296W_Vertical
V1: DC 62V; not fitted
V2: DC -62V; not fitted
V3: VSIN; not fitted
WJ4001, WJ4002, WJ4003, WJ4005, WJ4008, WJ4013: Wire Jumper; J_10.16mm
WJ4004, WJ4006, WJ4007, WJ4009, WJ4010, WJ4011, WJ4012: Wire Jumper; J_12.7mm

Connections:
0: C4001.2, C4002.1, C4013.2, CNT4004.1, CNT4007.1, CNT4008.2, R4001.1, R4002.2, R4015.1, RG1.1, RLOAD1.2, V1.2, V2.2
+62V: C4001.1, C4009.1, CNT4001.1, D4001.2 (A), D4007.1 (K), Q4011.2 (C), Q4013.2 (C), Q4014.2 (C), Q4015.2 (C), R4003.1, R4013.1, R4017.1, R4019.1, V1.1
-62V: C4002.2, C4011.2, CNT4002.1, D4005.1 (K), D4008.2 (A), Q4012.2 (C), Q4016.2 (C), Q4017.2 (C), Q4018.2 (C), R4011.2, R4012.2, R4014.2, R4016.2, R4021.2, V2.1
AGND: C4004.2, C4005.2, CNT4005.2, R4007.2, RG1.2, V3.2, WJ4002.2
INPUT: CNT4005.1, R4009.2, V3.1
unnamed: C4003.2, C4004.1, R4009.1
unnamed: C4005.1, R4010.2
unnamed: C4006.1, R4008.1, WJ4003.1
unnamed: C4007.1, WJ4004.1
unnamed: C4013.1, R4039.2
unnamed: CNT4003.1, WJ4001.1
unnamed: CNT4008.1, WJ4013.2
unnamed: D4001.1 (K), D4002.2 (A)
unnamed: D4002.1 (K), Q4001.2 (B), R4002.1
unnamed: C4010.2, D4003.2 (A), Q4006.1 (E), Q4009.2 (B), WJ4004.2
unnamed: D4003.1 (K), R4014.1
unnamed: D4004.2 (A), Q4007.2 (B), R4015.2
unnamed: D4004.1 (K), D4005.2 (A)
unnamed: D4006.2 (A), R4017.2
unnamed: C4008.2, D4006.1 (K), Q4008.2 (B), R4018.1
unnamed: Q4001.3 (C), R4004.1, R4005.1, R4006.1
unnamed: Q4001.1 (E), R4003.2
unnamed: C4003.1, Q4002.2 (B), R4007.1
unnamed: C4006.2, Q4002.3 (C), Q4005.3 (C), Q4006.2 (B)
unnamed: Q4002.1 (E), R4004.2, RT4001.1
unnamed: Q4003.2 (B), R4008.2, R4010.1
unnamed: Q4003.3 (C), Q4004.2 (B), Q4004.3 (C), Q4005.2 (B)
unnamed: Q4003.1 (E), R4005.2, RT4001.3
unnamed: Q4004.1 (E), R4011.1
unnamed: Q4005.1 (E), R4012.1
unnamed: Q4006.3 (C), R4013.2
unnamed: Q4007.3 (C), R4018.2
unnamed: C4007.2, Q4007.1 (E), R4016.1
unnamed: C4008.1, Q4008.3 (C), R4020.1
unnamed: C4009.2, Q4008.1 (E), R4019.2
unnamed: C4010.1, Q4009.3 (C), R4022.2
unnamed: C4011.1, Q4009.1 (E), R4021.1
unnamed: Q4010.2 (B), R4023.2, R4024.1, WJ4008.1
unnamed: C4012.1, Q4010.3 (C), Q4011.1 (B), R4020.2, R4023.1, WJ4005.1
unnamed: C4012.2, Q4010.1 (E), RT4002.2, WJ4009.1
unnamed: Q4011.3 (E), R4025.1, WJ4010.2
unnamed: Q4012.1 (B), R4022.1, WJ4009.2
unnamed: Q4012.3 (E), R4026.2, WJ4011.2
unnamed: Q4013.1 (B), R4027.2
unnamed: Q4013.3 (E), R4028.1
unnamed: Q4014.1 (B), R4029.2
unnamed: Q4014.3 (E), R4030.1
unnamed: Q4015.1 (B), R4031.2
unnamed: Q4015.3 (E), R4032.1, WJ4012.2
unnamed: Q4016.1 (B), R4033.1
unnamed: Q4016.3 (E), R4034.2
unnamed: Q4017.1 (B), R4035.1
unnamed: Q4017.3 (E), R4036.2
unnamed: Q4018.1 (B), R4037.1
unnamed: Q4018.3 (E), R4038.2
unnamed: R4001.2, WJ4001.2, WJ4002.1
unnamed: R4006.2, RT4001.2
unnamed: R4024.2, RT4002.1
unnamed: R4027.1, R4029.1, R4031.1, WJ4010.1
unnamed: R4033.2, R4035.2, R4037.2, WJ4011.1
unnamed: RNTC4001.1, WJ4006.2
unnamed: RNTC4001.2, WJ4007.2
unnamed: WJ4005.2, WJ4006.1
unnamed: WJ4007.1, WJ4008.2
unnamed: WJ4012.1, WJ4013.1
OUTPUT: CNT4006.1, L4001.2, R4040.1, RLOAD1.1
PW_OUT: D4007.2 (A), D4008.1 (K), L4001.1, R4025.2, R4026.1, R4028.2, R4030.2, R4032.2, R4034.1, R4036.1, R4038.1, R4039.1, R4040.2, WJ4003.2

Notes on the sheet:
.options abstol=1u
dc 0 ac 1 sin(0 2.192 1K 0 0)
.options reltol=0.01
.title 350W CLASS-B POWER AMPLIFIER MAIN-CIRCUIT FOR 4-OHMS OUTPUT LOAD
dc 0 ac 1 sin(0 0.775 1K 0 0)
.PARAM BIAS=0.333
.PARAM OFFSET=0.333
dc 0 ac 1 sin(0 1.096 1K 0 0)
PROTECT SENSING SOURCE
-0UTPUT/SPK
-VCC
INPUT: 0.775V RMS MAX.
POWER GROUND
+VCC
+62V OPERATING VOLTAGE
-62V OPERATING VOLTAGE
OUTPUT: 37.5V RMS 350 WATTS @ 4-OHMS
AUDIO GROUND
+0UTPUT/SPK
PGND
OFFSET NULL
AGND
OUTPUT STAGE BIAS VOLTAGE ADV.

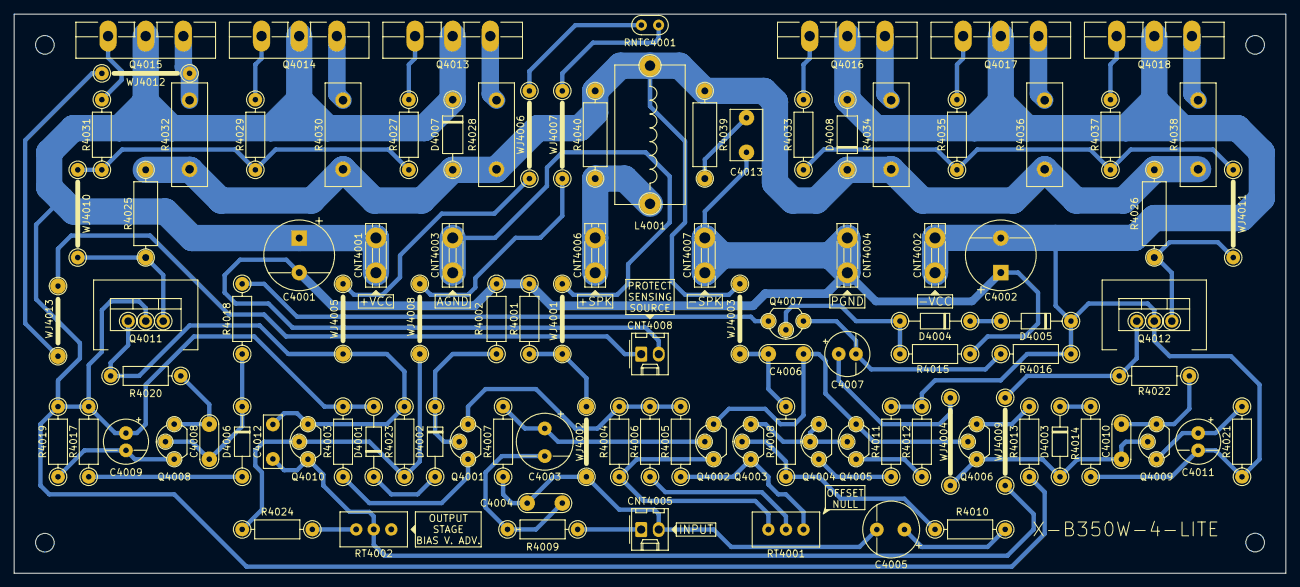
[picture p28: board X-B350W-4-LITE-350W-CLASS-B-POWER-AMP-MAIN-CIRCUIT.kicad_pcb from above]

Board: 2 copper layers, 184.2 x 81.0 mm, 104 parts (1 on the bottom side), 67 nets.
